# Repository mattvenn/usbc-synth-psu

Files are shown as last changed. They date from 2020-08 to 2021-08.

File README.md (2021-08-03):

# USBC Synth PSU

* uses STUSB4500 to negotiate 12v or 15v from a USBC power bank
* uses 4 [DC/DC switchers](https://www.ti.com/product/TPS56339) to supply 12, 9, 5 and 3v outputs for my various synths
* resistors can be changed to set different output voltage
* JP1 can be bridged and 12v DC/DC components not placed if power bank can supply 12v.

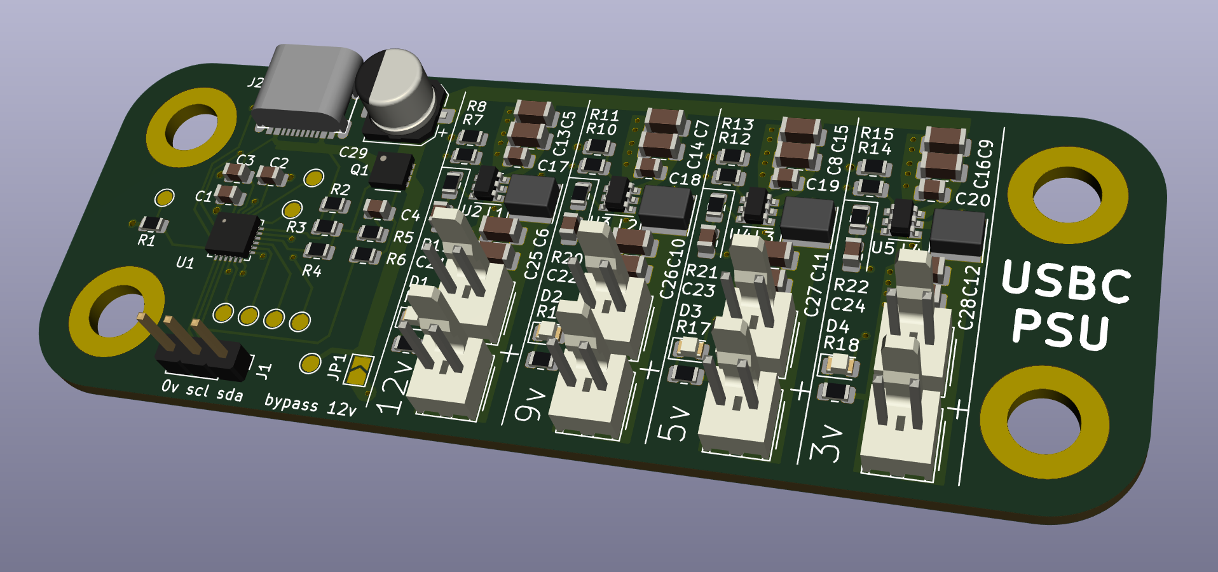
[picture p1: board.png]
board


[PDF schematic](schematic.pdf)

[gerbers](synth-psu-2020-09-01-fab.zip)

[bom](synth-psu-bom.csv)

# Project log

For build notes, problems and fixes, please check the [project log](docs/log.md)

# Errata

* hole size is 5.3mm, should be 6 for M5 - fixed in PCB, not in gerbers

# Future improvements

* make the switcher parts snap-offable

# Resources

* proposed USBC charger: https://www.amazon.es/AUKEY-10000-mAh-Delivery-3-0-Cargador-Port%C3%A1til/dp/B07B4RQ47B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
* STUSB4500 datasheet https://www.st.com/en/interfaces-and-transceivers/stusb4500.html
* sparkfun USB PD product https://www.sparkfun.com/products/15801
* tindie USB PD product: https://github.com/oxplot/fabpide2
* sparkfun how to use their PD board: https://learn.sparkfun.com/tutorials/power-delivery-board---usb-c-qwiic-hookup-guide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

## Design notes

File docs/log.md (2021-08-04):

# psu design

## test

To see if powering the audio gear with dc/dc will be a problem, I tried powering a PO-12 with a different dc/dc switcher at 3.3v

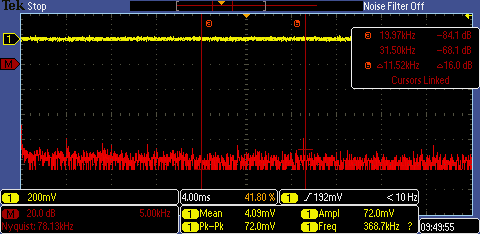
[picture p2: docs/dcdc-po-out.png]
fft audio noise


## functional todo

* looks like aukey charger only goes up to 12v, so add a jumper to short out one of the DC switchers - done
* check noise with a 3v generated supply into PO - done

## schematic todo

* add part numbers - done
* enable switchers only if PD is good? - no, as PD is open drain and would need an inverter, plus DCDC float to enable
* check max input dc/dc - 5v! need to find another - how about https://www.ti.com/product/TPS56339#product-details##pps - done
* calculate all R1 & R2 for dc/dc - done, used TI webench
* calculate all LED R  - done
* add more psu outputs (or can remove the 12v one?) - done
* do we need 5v? (aukey can do 2x usb 5v as well as PD on usbC) - done anyway
* mosfet and check pinout - done
* double check pinout and wiring of usb chip - done

## pcb todo

* check gerbers against other designs for pinout - done
* check space for molex header - done
* mount holes fit 20mm grid - done

# bring up

* check for shorts between vbus (testpoint) and gnd (corner holes)
* plug in usbC PSU, if the STUSB4500 is working then it will negotiate 5v and turn on the FET
* check the output rail (testpoint) is 5v
* if you have DC/DC switchers with output < 5v they should turn on and LEDs should light
* connect up your I2C controller and follow programming notes below

# programming

The NVM of the STUSB4500 needs to be programmed to sink more than the highest output you want. 
For example 15v (for 12v DC/DC converter).

The Aukey USBC powerbank I bought can only supply up to 12v, so I set the number of PDOs to be 2, and 
ask for 12v. Then I bridge JP1 and don't place any of the DC/DC for the 12v supply.

Here is the [Sparkfun demo firmware I used](../firmware/src/program.ino). To do the programming I used platformio with an Arduino Uno.

Connect the I2C pins and ground to header J1 on the pcb. *SDA and SCL will both need pullups.*

To build and upload, run:

    pio run --target upload

Then open the serial port to see the results.

    pio device monitor -b 115200

# issues

* the Aukey powerbank often gets into a mode where it doesn't do the negotiation (can check the cc lines on scope). In this case output will always be off if setPowerAbove5vOnly() is set.
* the DJI USBC power brick doesn't work at all, and I have no idea how it could as the output is normal USB standard A type.
## 9v switcher waveform results

Results of 9v switcher supplied with 12v from USBC powerbank at 4 different loads.

### 50mA load
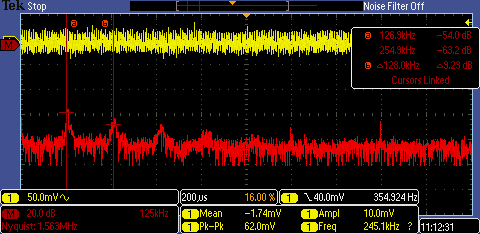
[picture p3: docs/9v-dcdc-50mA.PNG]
9v dcdc 50mA


### 100mA load
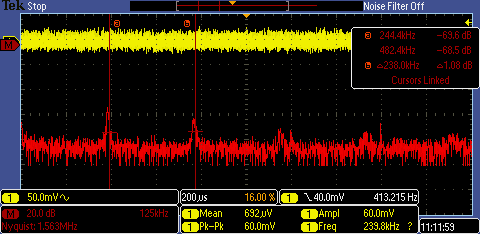
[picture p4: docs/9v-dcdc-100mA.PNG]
9v dcdc 100mA


### 500mA load
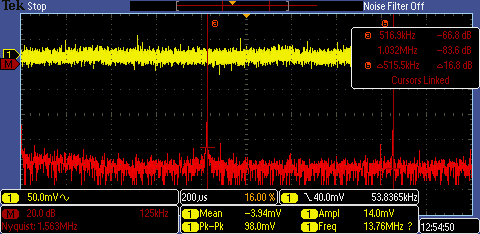
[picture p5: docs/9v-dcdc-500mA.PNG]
9v dcdc 500mA


### 1000mA load
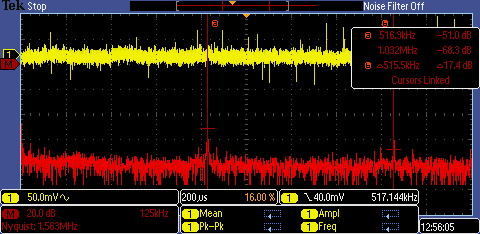
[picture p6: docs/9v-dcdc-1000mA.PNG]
9v dcdc 1000mA


Main spikes look way above audio frequency so hopefully switching noise won't be audible.
For loads <500mA (most likely for my case) AC pk-pk is between 60 and 100mV.

# Noise issues

I experienced some noise issues with the PSU and [documented the investigation here](noise_issue.md)

# Connection issues Wed 16 Sep 10:35:35 CEST 2020

Sometimes the board can't get power from the USBC power supply. This seems intermittent.
The LEDs flash and then go out. I thought it could be to do with lack of charge in the USBC power bank, bad cable,
or the big 100uF cap charging and dropping the voltage low enough for the STUSB4500 to cut off the power.

With the synths, it has stopped being able to power the kaoss pad. As soon as it is plugged in or turned on
the connection is cut.

I checked today with the scope and with enough load the voltage drops and the chip does cut off power (as expected).
The low voltage setting in the firmware was 0.6v, so with a bad cable this could explain it. However it had worked
previously.

I have updated the firmware to allow a 2v voltage drop and have tested up to a 2A load suddenly connecting. At 2A
the voltage drop becomes 2v and the supply is turned off.

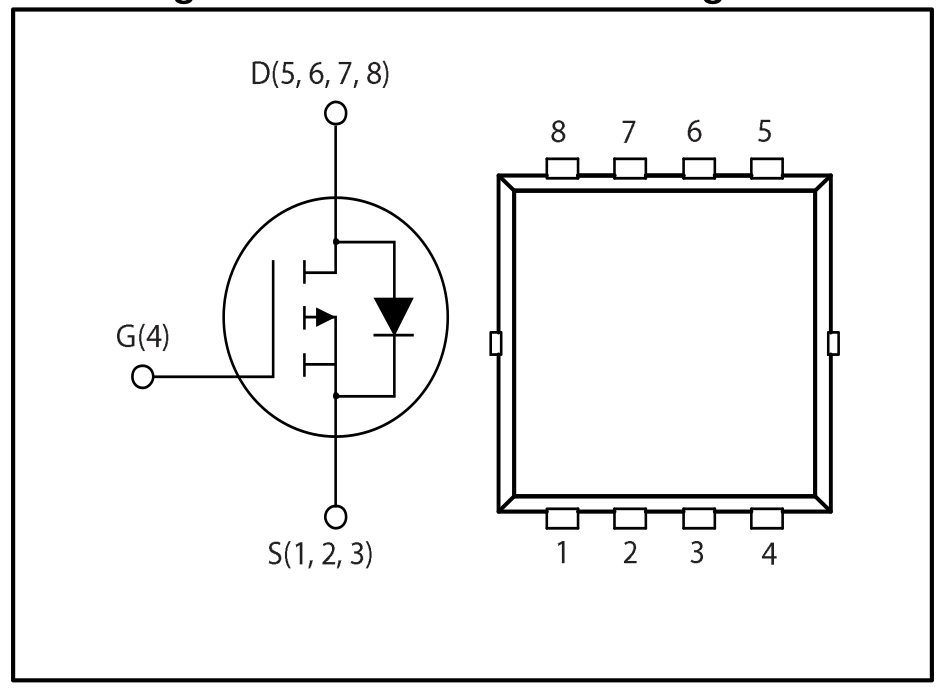
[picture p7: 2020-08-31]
docs/mosfet.png

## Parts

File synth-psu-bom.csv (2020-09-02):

Ref | Qnty | Value | Cmp name | Manufacturer | Partnum
C1, C2, C3, | 3 | 1uF | C | Kemet | C0805C105K3PACTU
C4, C17, C18, C19, C20, C21, C22, C23, C24, | 9 | 100n | C | Kemet | C0805C104Z3VACTU
C5, C7, C8, C9, C13, C14, C15, C16, | 8 | 10u 25v | C | Multicomp | MC1206X106K250CT
C6, C10, C11, C12, C25, C26, C27, C28, | 8 | 22u 16v | C | Kemet | C1206C226M4PACTU
C29, | 1 | 100uf 25v | CP | Panasonic | EEEFKE101XAP
D1, D2, D3, D4, | 4 | LED | LED | Kingbright | KPT-2012EC
H1, H2, H3, H4, | 4 | MountingHole_Pad | MountingHole_Pad
J1, | 1 | Conn_01x03_Male | Conn_01x03_Male
J2, | 1 | USB_C_Receptacle_16pin | USB_C_Receptacle_16pin
J3, J4, J5, J6, J7, J8, J9, J10, | 8 | Conn_01x02_Male | Conn_01x02_Male | Molex | 22-23-2021
JP1, | 1 | SolderJumper_2_Open | SolderJumper_2_Open
L1, L2, L3, L4, | 4 | 6.8uH | L | Vishay | IFSC1515AHER6R8M01
Q1, | 1 | Q_PMOS_DSG | Q_PMOS_DSG | ST | STL6P3LLH6
R1, R3, R10, | 3 | 100k | R | Multicomp | MCWR08X1003FTL
R2, R6, | 2 | 1k | R | Multicomp | MCMR08X1001FTL
R4, | 1 | 22k | R | Multicomp | MCWR08X2202FTL
R5, R18, | 2 | 100r | R | Multicomp | MCWR08X1000FTL
R7, | 1 | 140k | R | Multicomp | MCWR08X1403FTL
R8, R11, R13, R15, | 4 | 10k | R | Multicomp | MCMR08X1002FTL
R9, | 1 | 660r | R | Multicomp | MCMR08X6650FTL
R12, | 1 | 51k | R | Multicomp | MCWR08X5102FTL
R14, | 1 | 27.4k | R | Multicomp | MCMR08X2742FTL
R16, | 1 | 470r | R | Multicomp | MCWR08X4700FTL
R17, | 1 | 200r | R | Multicomp | MCWR08X2000FTL
R19, R20, R21, R22, | 4 | 30R | R | Multicomp | MCWR08X30R0FTL
TP1, TP2, TP3, TP4, TP5, TP6, TP7, TP8, TP9, TP10, TP11, | 11 | TestPoint | TestPoint
U1, | 1 | STUSB4500QTR | STUSB4500QTR | ST | STUSB4500QTR
U2, U3, U4, U5, | 4 | TPS56339 | TPS562200 | Texas Instruments | TPS56339DDCR

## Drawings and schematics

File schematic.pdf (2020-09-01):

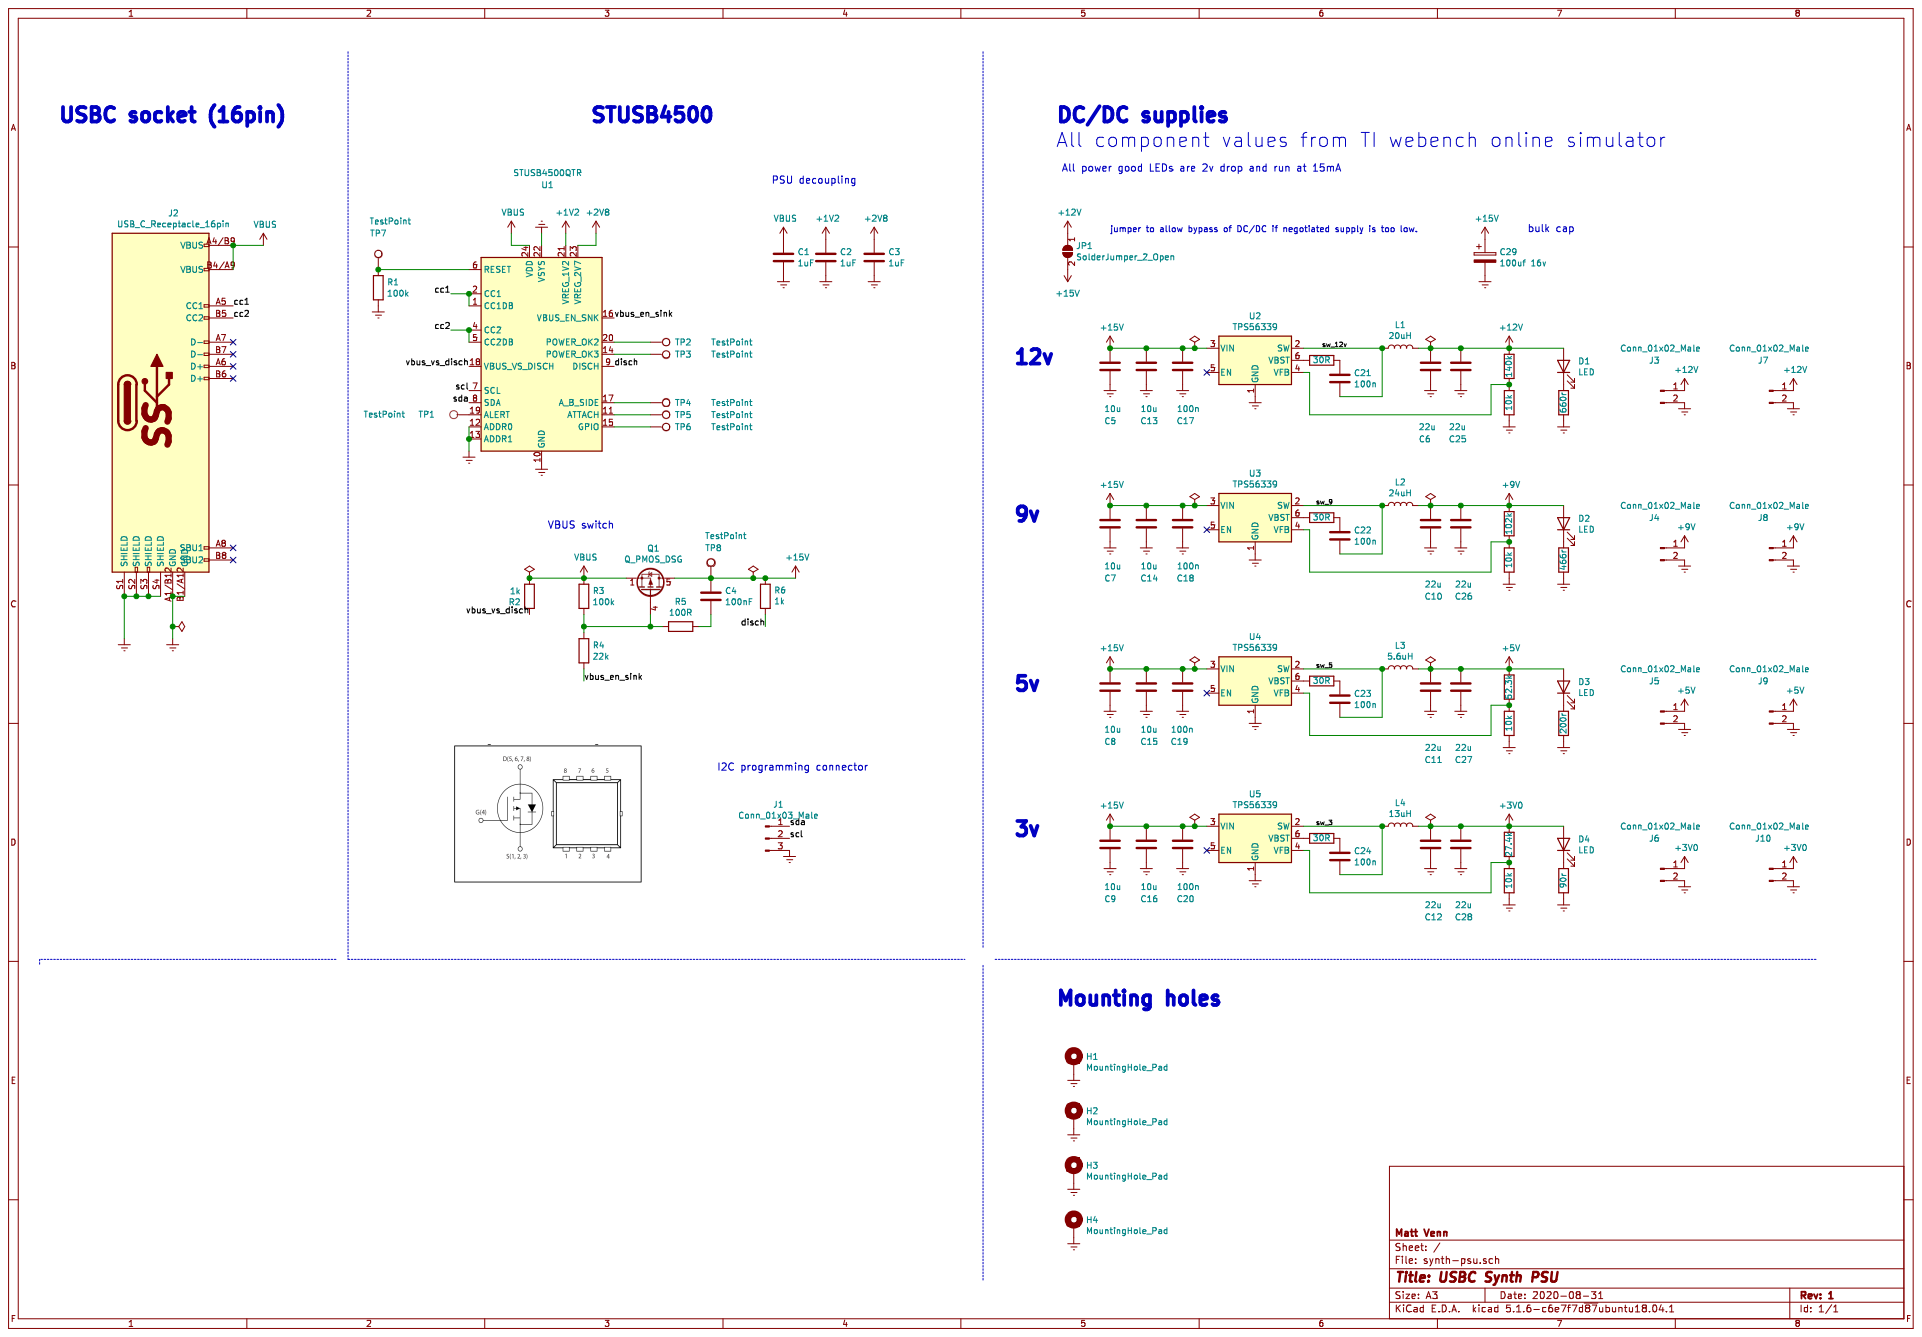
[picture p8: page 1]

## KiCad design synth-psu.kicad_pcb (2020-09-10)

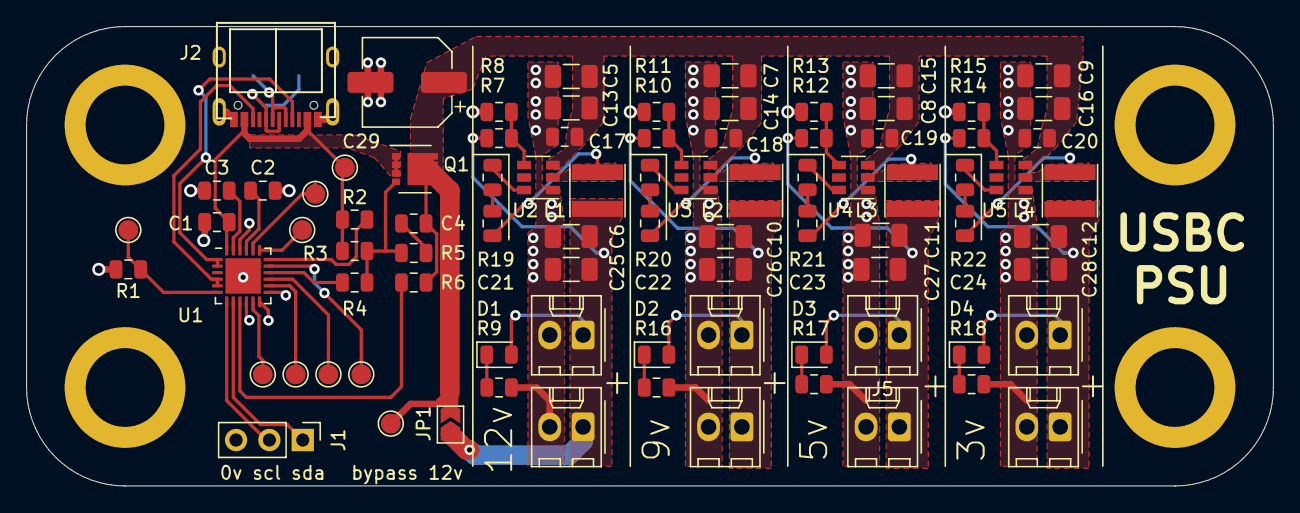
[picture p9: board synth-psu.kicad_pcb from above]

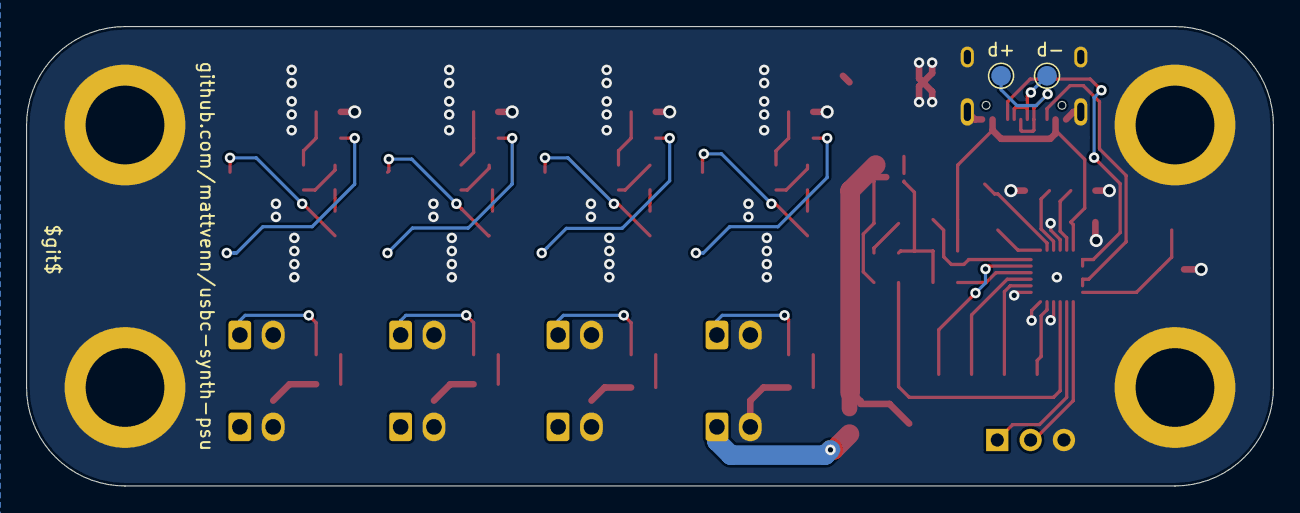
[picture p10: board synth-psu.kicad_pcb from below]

Board: 2 copper layers, 95.0 x 35.0 mm, 91 parts (2 on the bottom side), 47 nets.

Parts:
C1, C2, C3: 1uF; C_0805_2012Metric
C4, C17, C18, C19, C20, C21, C22, C23, C24: 100n; C_0805_2012Metric
C5, C7, C8, C9, C13, C14, C15, C16: 10u 25v; C_1206_3216Metric
C6, C10, C11, C12, C25, C26, C27, C28: 22u 16v; C_1206_3216Metric
C29: 100uf 25v; CP_Elec_6.3x5.9
D1, D2, D3, D4: LED; LED_0805_2012Metric
H1, H2, H3, H4: MountingHole_Pad; MountingHole_5.3mm_M5_DIN965_Pad
J1: Conn_01x03_Male; PinHeader_1x03_P2.54mm_Vertical
J2: USB_C_Receptacle_16pin; usb-c-16smt
J3, J4, J5, J6, J7, J8, J9, J10: Conn_01x02_Male; Molex_KK-254_AE-6410-02A_1x02_P2.54mm_Vertical
JP1: SolderJumper_2_Open; SolderJumper-2_P1.3mm_Open_TrianglePad1.0x1.5mm
L1, L2, L3, L4: 6.8uH; L_Taiyo-Yuden_NR-40xx
Q1: Q_PMOS_DSG; VSON-8_3.3x3.3mm_P0.65mm_NexFET
R1, R3, R10: 100k; R_0805_2012Metric
R2, R6: 1k; R_0805_2012Metric
R4: 22k; R_0805_2012Metric
R5, R18: 100r; R_0805_2012Metric
R7: 140k; R_0805_2012Metric
R8, R11, R13, R15: 10k; R_0805_2012Metric
R9: 660r; R_0805_2012Metric
R12: 51k; R_0805_2012Metric
R14: 27.4k; R_0805_2012Metric
R16: 470r; R_0805_2012Metric
R17: 200r; R_0805_2012Metric
R19, R20, R21, R22: 30R; R_0805_2012Metric
TP1, TP2, TP3, TP4, TP5, TP6, TP7, TP8, TP9, TP10, TP11: TestPoint; TestPoint_Pad_D1.5mm
U1: STUSB4500QTR; QFN-24-1EP_4x4mm_P0.5mm_EP2.7x2.7mm
U2, U3, U4, U5: TPS56339; SOT-23-6

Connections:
+1V2: C2.1, U1.21
+2V8: C3.1, U1.23
+3V0: C12.1, C28.1, D4.2, J6.1, J10.1, L4.2, R14.2
+5V: C11.1, C27.1, D3.2, J5.1, J9.1, L3.2, R12.2
+9V: C10.1, C26.1, D2.2, J4.1, J8.1, L2.2, R10.2
+12V: C6.1, C25.1, D1.2, J3.1, J7.1, JP1.1, L1.2, R7.2
+15V: C4.1, C5.1, C7.1, C8.1, C9.1, C13.1, C14.1, C15.1, C16.1, C17.1, C18.1, C19.1, C20.1, C29.1, JP1.2, Q1.5, R6.2, TP8.1, U2.3, U3.3, U4.3, U5.3
/cc1: J2.A5, U1.1, U1.2
/cc2: J2.B5, U1.4, U1.5
/d+: J2.A6, J2.B6, TP11.1
/d-: J2.A7, J2.B7, TP10.1
/disch: R6.1, U1.9
/scl: J1.2, U1.7
/sda: J1.1, U1.8
/sw_3: C24.2, L4.1, U5.2
/sw_5: C23.2, L3.1, U4.2
/sw_9: C22.2, L2.1, U3.2
/sw_12v: C21.2, L1.1, U2.2
/vbus_en_sink: R4.2, U1.16
/vbus_vs_disch: R2.2, U1.18
Earth: C1.2, C2.2, C3.2, C5.2, C6.2, C7.2, C8.2, C9.2, C10.2, C11.2, C12.2, C13.2, C14.2, C15.2, C16.2, C17.2, C18.2, C19.2, C20.2, C25.2, C26.2, C27.2, C28.2, C29.2, H1.1, H2.1, H3.1, H4.1, J1.3, J2.A1/B12, J2.B1/A12, J2.S1, J2.S2, J2.S3, J2.S4, J3.2, J4.2, J5.2, J6.2, J7.2, J8.2, J9.2, J10.2, R1.2, R8.1, R9.1, R11.1, R13.1, R15.1, R16.1, R17.1, R18.1, U1.10, U1.12, U1.13, U1.22, U1.25, U2.1, U3.1, U4.1, U5.1
unnamed: C4.2, R5.1
unnamed: C21.1, R19.2
unnamed: C22.1, R20.2
unnamed: C23.1, R21.2
unnamed: C24.1, R22.2
unnamed: D1.1, R9.2
unnamed: D2.1, R16.2
unnamed: D3.1, R17.2
unnamed: D4.1, R18.2
unnamed: Q1.4, R3.2, R4.1, R5.2
unnamed: R1.1, TP7.1, U1.6
unnamed: R7.1, R8.2, U2.4
unnamed: R10.1, R11.2, U3.4
unnamed: R12.1, R13.2, U4.4
unnamed: R14.1, R15.2, U5.4
unnamed: R19.1, U2.6
unnamed: R20.1, U3.6
unnamed: R21.1, U4.6
unnamed: R22.1, U5.6
unnamed: TP1.1, U1.19
unnamed: TP2.1, U1.20
unnamed: TP3.1, U1.14
unnamed: TP4.1, U1.17
unnamed: TP5.1, U1.11
unnamed: TP6.1, U1.15
VBUS: C1.1, J2.A4/B9, J2.B4/A9, Q1.1, Q1.2, Q1.3, R2.1, R3.1, TP9.1, U1.24

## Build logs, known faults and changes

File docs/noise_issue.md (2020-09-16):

# Noise issue

After plugging the Kaoss pad and volca together I heard a lot of bad noise.

Posted in 1bit squared [electronics discussion channel](https://discord.com/channels/613131135903596547/701517294697840700/755165090306719846) (registration required but info copied here).

Connections and results shown in this image:

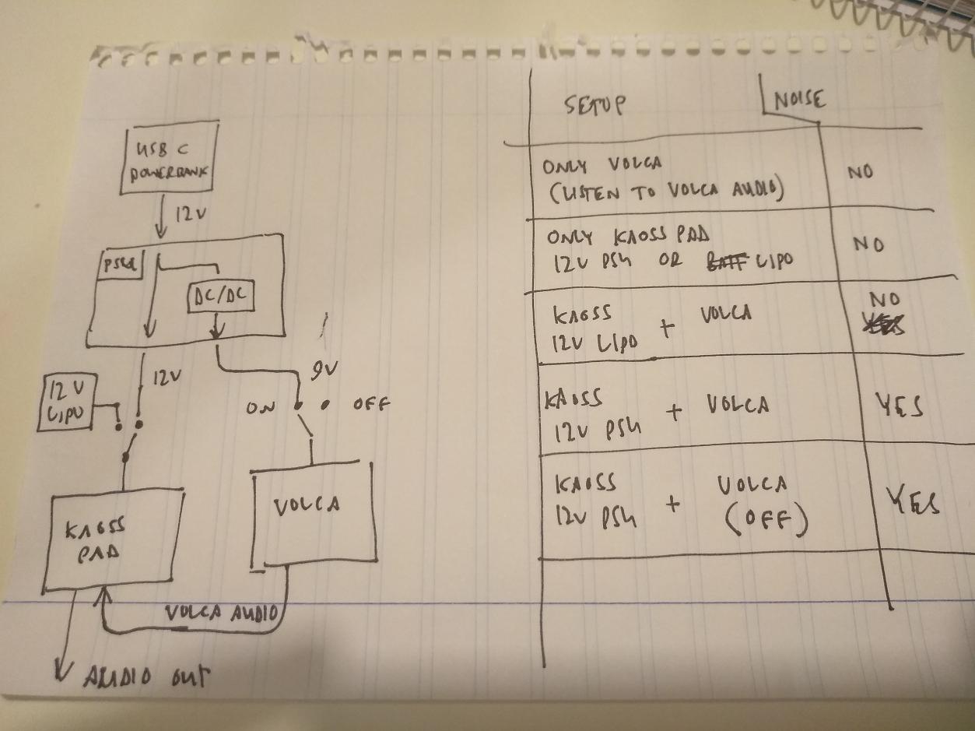
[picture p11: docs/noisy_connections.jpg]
connections


Noise recording is [here](noise.wav)

User Obliterous on the discord thought it would be a ground loop related issue and suggested making a common mode choke with a decoupling capacitor on each side.

I made a test board:

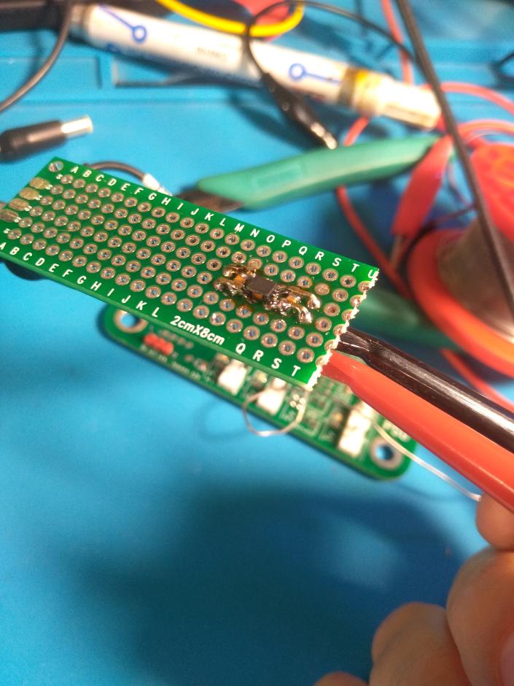
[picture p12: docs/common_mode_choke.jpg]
common mode choke


And tested it with a 10k -> 10M sweep. Green is input and yellow is output. The filter removes all the signal above about 100khz.

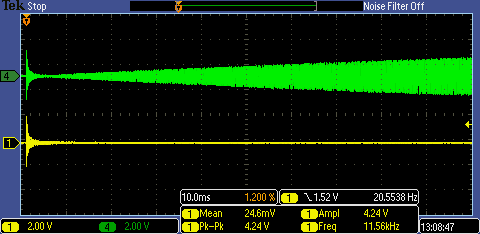
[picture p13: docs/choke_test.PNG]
choke test


I will test this in between the Kaoss pad and the PSU.

# Wed 16 Sep 10:38:31 CEST 2020

Tried yesterday but now the PSU can't even power the kaoss pad. See the main project log for notes on this.
Did try with the POs and they have the same problem that I couldn't resolve with the choke or the audio filter.

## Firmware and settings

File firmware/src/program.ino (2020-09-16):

/*
  Writing the Settings to the STUSB4500 Power Delivery Board
  By: Alex Wende
  SparkFun Electronics
  Date: February 6th, 2020
  License: This code is public domain but you buy me a beer if you use this and we meet someday (Beerware license).
  Feel like supporting our work? Buy a board from SparkFun!
  https://www.sparkfun.com/products/15801
  
  This example demonstrates how to change the NVM settings saved to the STUSB4500
  
  Quick-start:
  - Use a SparkFun RedBoard Qwiic -or- attach the Qwiic Shield to your Arduino/Photon/ESP32 or other
  - Uncomment and modify the variables of the functions you want to change
  - Upload the sketch
  - Plug the Power Delivery Board onto the RedBoard/shield
  - Open the serial monitor and set the baud rate to 115200
  - The RedBoard will connect to the Power Delivery Board over I2C and print out all of the settings saved.
*/
// Include the SparkFun STUSB4500 library.
// Click here to get the library: http://librarymanager/All#SparkFun_STUSB4500

#include <Wire.h>
#include <SparkFun_STUSB4500.h>

STUSB4500 usb;

void setup() 
{
  Serial.begin(115200);
  Wire.begin(); //Join I2C bus
  
  delay(500);
  
  /* The Power Delivery board uses the default settings with address 0x28 using Wire.
  
     Opionally, if the address jumpers are modified, or using a different I2C bus,
     these parameters can be changed here. E.g. usb.begin(0x29,Wire1)
  
     It will return true on success or false on failure to communicate. */
  if(!usb.begin())
  {
    Serial.println("Cannot connect to STUSB4500.");
    Serial.println("Is the board connected? Is the device ID correct?");
    while(1);
  }
  
  Serial.println("Connected to STUSB4500!");
  delay(100);

  /* Set Number of Power Data Objects (PDO) 1-3 */
  usb.setPdoNumber(2);

  /* PDO1
   - Voltage fixed at 5V
   - Current value for PDO1 0-5A, if 0 used, FLEX_I value is used
   - Under Voltage Lock Out (setUnderVoltageLimit) fixed at 3.3V
   - Over Voltage Lock Out (setUpperVoltageLimit) 5-20%
  */
//  usb.setCurrent(1,0.5);
//  usb.setUpperVoltageLimit(1,20);

  /* PDO2
   - Voltage 5-20V
   - Current value for PDO2 0-5A, if 0 used, FLEX_I value is used
   - Under Voltage Lock Out (setUnderVoltageLimit) 5-20%
   - Over Voltage Lock Out (setUpperVoltageLimit) 5-20%
  */
  usb.setVoltage(2,12.0);
  usb.setCurrent(2,1.5);
  usb.setLowerVoltageLimit(2,16);	// as low as 10v
  usb.setUpperVoltageLimit(2,5); 	// as high as 12.6v

  /* PDO3
   - Voltage 5-20V
   - Current value for PDO3 0-5A, if 0 used, FLEX_I value is used
   - Under Voltage Lock Out (setUnderVoltageLimit) 5-20%
   - Over Voltage Lock Out (setUpperVoltageLimit) 5-20%
  */
  /*
  usb.setVoltage(3,15.0);
  usb.setCurrent(3,1.0);
  usb.setLowerVoltageLimit(3,5);
  usb.setUpperVoltageLimit(3,5);
  */

  /* Flexible current value common to all PDOs */
//  usb.setFlexCurrent(1.0);

  /* Unconstrained Power bit setting in capabilities message sent by the sink */
//  usb.setExternalPower(false);

  /* USB 2.0 or 3.x data communication capability by sink system */
//  usb.setUsbCommCapable(false);

  /* Selects POWER_OK pins configuration
     0 - Configuration 1
     1 - No applicable
     2 - Configuration 2 (default)
     3 - Configuration 3
  */
  usb.setConfigOkGpio(2);

  /* Selects GPIO pin configuration
     0 - SW_CTRL_GPIO
     1 - ERROR_RECOVERY
     2 - DEBUG
     3 - SINK_POWER
  */
//  usb.setGpioCtrl(3);

  /* Selects VBUS_EN_SNK pin configuration */
  usb.setPowerAbove5vOnly(true);

  /* In case of match, selects which operating current from the sink or the
     source is to be requested in the RDO message */
//  usb.setReqSrcCurrent(false);

  /* Write and save settings to STUSB4500 */
  usb.write();
  
  /* Read the NVM settings to verify the new settings are correct */
  usb.read();

  Serial.println("New Parameters:\n");

  /* Read the Power Data Objects (PDO) highest priority */
  Serial.print("PDO Number: ");
  Serial.println(usb.getPdoNumber());

  /* Read settings for PDO1 */
  Serial.println();
  Serial.print("Voltage1 (V): ");
  Serial.println(usb.getVoltage(1));
  Serial.print("Current1 (A): ");
  Serial.println(usb.getCurrent(1));
  Serial.print("Lower Voltage Tolerance1 (%): ");
  Serial.println(usb.getLowerVoltageLimit(1));
  Serial.print("Upper Voltage Tolerance1 (%): ");
  Serial.println(usb.getUpperVoltageLimit(1));
  Serial.println();

  /* Read settings for PDO2 */
  Serial.print("Voltage2 (V): ");
  Serial.println(usb.getVoltage(2));
  Serial.print("Current2 (A): ");
  Serial.println(usb.getCurrent(2));
  Serial.print("Lower Voltage Tolerance2 (%): ");
  Serial.println(usb.getLowerVoltageLimit(2));
  Serial.print("Upper Voltage Tolerance2 (%): ");
  Serial.println(usb.getUpperVoltageLimit(2));
  Serial.println();

  /* Read settings for PDO3 */
  Serial.print("Voltage3 (V): ");
  Serial.println(usb.getVoltage(3));
  Serial.print("Current3 (A): ");
  Serial.println(usb.getCurrent(3));
  Serial.print("Lower Voltage Tolerance3 (%): ");
  Serial.println(usb.getLowerVoltageLimit(3));
  Serial.print("Upper Voltage Tolerance3 (%): ");
  Serial.println(usb.getUpperVoltageLimit(3));
  Serial.println();

  /* Read the flex current value */
  Serial.print("Flex Current: ");
  Serial.println(usb.getFlexCurrent());

  /* Read the External Power capable bit */
  Serial.print("External Power: ");
  Serial.println(usb.getExternalPower());

  /* Read the USB Communication capable bit */
  Serial.print("USB Communication Capable: ");
  Serial.println(usb.getUsbCommCapable());

  /* Read the POWER_OK pins configuration */
  Serial.print("Configuration OK GPIO: ");
  Serial.println(usb.getConfigOkGpio());

  /* Read the GPIO pin configuration */
  Serial.print("GPIO Control: ");
  Serial.println(usb.getGpioCtrl());

  /* Read the bit that enables VBUS_EN_SNK pin only when power is greater than 5V */
  Serial.print("Enable Power Only Above 5V: ");
  Serial.println(usb.getPowerAbove5vOnly());
  
  /* Read bit that controls if the Source or Sink device's 
     operating current is used in the RDO message */
  Serial.print("Request Source Current: ");
  Serial.println(usb.getReqSrcCurrent());
}

void loop()
{
}

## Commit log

2020-08-31 footprints and initial layout
    [synth-psu.kicad_pcb, synth-psu.sch]
2020-08-31 need to find a new dc/dc. also allow bypass of 12v switcher
    [synth-psu.sch]
2020-08-31 neaten schematic and export board pic and schematic pic
    [synth-psu.sch]
2020-08-31 alternative switcher
2020-08-31 mosfet footprint and lib, routed stusb4500
    [synth-psu.kicad_pcb, synth-psu.sch]
2020-08-31 part number for mosfet
    [synth-psu.sch]
2020-09-01 change dc/dc to new part and did layout
    [synth-psu.kicad_pcb, synth-psu.sch]
2020-09-01 removed 1 set of supply sockets to fit molex polarised kk, silk screen
    [synth-psu.kicad_pcb, synth-psu.sch]
2020-09-01 led resistors
    [synth-psu.sch]
2020-09-01 fixed silk overlap on +
    [synth-psu.kicad_pcb]
2020-09-01 add gerber link to readme
2020-09-01 updated board pic
2020-09-01 updated schematic
2020-09-01 fix part number on dc switchers
2020-09-01 link to switcher
2020-09-01 more neatening
    [synth-psu.sch]
2020-09-01 shortened vfb traces
    [synth-psu.kicad_pcb]
2020-09-01 reexport gerber
2020-09-01 continue tweaking dc/dc copper pours
    [synth-psu.kicad_pcb]
2020-09-01 add vbus testpoint
    [synth-psu.kicad_pcb, synth-psu.sch]
2020-09-02 bom wip
2020-09-02 usb test pads, add some component order codes, check sizes of caps
    [synth-psu.sch]
2020-09-02 usb test pads
    [synth-psu.kicad_pcb]
2020-09-02 ordered pcbs
2020-09-02 part numbers
    [synth-psu.sch]
2020-09-02 bom link
2020-09-10 push through bom changes to the pcb for the interactive bom viewer
    [synth-psu.kicad_pcb]
2020-09-10 fw updates to only ask for 12v
2020-09-10 fixed mount holes to 6mm
    [synth-psu.kicad_pcb]
2020-09-14 9v switcher test results
2020-09-14 add 1000mA test
2020-09-15 note on range of filter
2020-09-16 reduce lower voltage level to 10v (16%)
2021-08-04 working for 9v out
2021-08-04 notes on 9v supply
